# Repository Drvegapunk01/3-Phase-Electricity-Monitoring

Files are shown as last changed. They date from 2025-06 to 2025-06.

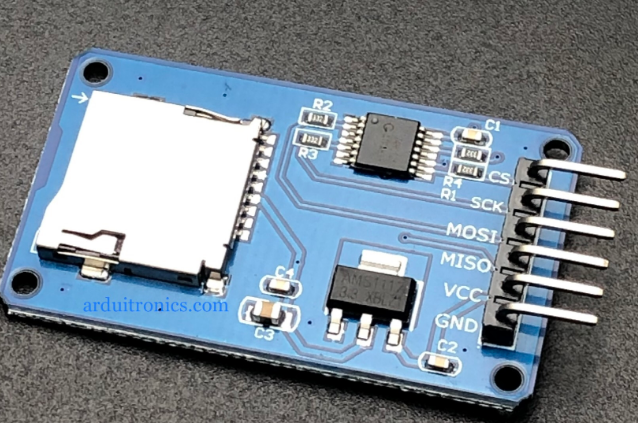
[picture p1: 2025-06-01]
PCB-File/3D-Picture/SD_card module.png

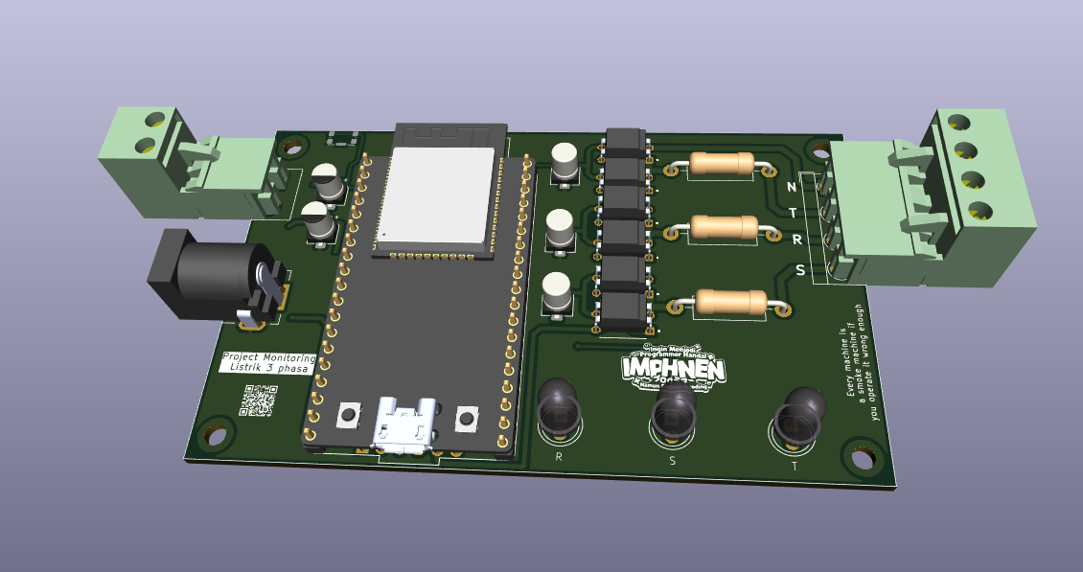
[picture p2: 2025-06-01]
PCB-File/3D-Picture/Screenshot 2025-06-01 153454.png

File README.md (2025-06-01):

# 3-Phase-Electricity-Monitoring

This project is a module to monitor the status of a 3-phase electricity supply and record any power outages. The data can be accessed wirelessly.
Currently, the features are limited to detecting the power state only.

This project was inspired by my father’s question about whether it’s possible to create a device that records power outages at the TV transmitter station where he works.

In the PCB, I use two optocouplers on each phase to capture the full-wave signal. Then, I filter the output with a capacitor to obtain a clean DC signal, which is connected to the ESP32’s I/O pins.

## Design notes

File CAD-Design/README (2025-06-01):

This design is still very bad and unfinished, and I am still learning more to make this case
and I use FreeCad to design this

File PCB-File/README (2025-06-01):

Software yang saya gunakan adalah Kicad 8.0

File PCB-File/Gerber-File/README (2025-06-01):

This is the output Gerber file of this project.

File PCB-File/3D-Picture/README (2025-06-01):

This is a 3D image of this PCB project, and there is also an image of the SD-Card module we are using.

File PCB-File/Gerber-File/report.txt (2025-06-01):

Warning: Width correction constrained.  The width correction value must be in the range of [0.000001 mm; 0.199999 mm] for the current design rules.
Plotted to 'E:\Project\ESP32 RST Monitoring\ESP32 RST Monitoring-F_Cu.gbr'.
Plotted to 'E:\Project\ESP32 RST Monitoring\ESP32 RST Monitoring-B_Cu.gbr'.
Plotted to 'E:\Project\ESP32 RST Monitoring\ESP32 RST Monitoring-F_Paste.gbr'.
Plotted to 'E:\Project\ESP32 RST Monitoring\ESP32 RST Monitoring-B_Paste.gbr'.
Plotted to 'E:\Project\ESP32 RST Monitoring\ESP32 RST Monitoring-F_Silkscreen.gbr'.
Plotted to 'E:\Project\ESP32 RST Monitoring\ESP32 RST Monitoring-B_Silkscreen.gbr'.
Plotted to 'E:\Project\ESP32 RST Monitoring\ESP32 RST Monitoring-F_Mask.gbr'.
Plotted to 'E:\Project\ESP32 RST Monitoring\ESP32 RST Monitoring-B_Mask.gbr'.
Plotted to 'E:\Project\ESP32 RST Monitoring\ESP32 RST Monitoring-Edge_Cuts.gbr'.
Created Gerber job file 'E:\Project\ESP32 RST Monitoring\ESP32 RST Monitoring-job.gbrjob'.
Info: Done.

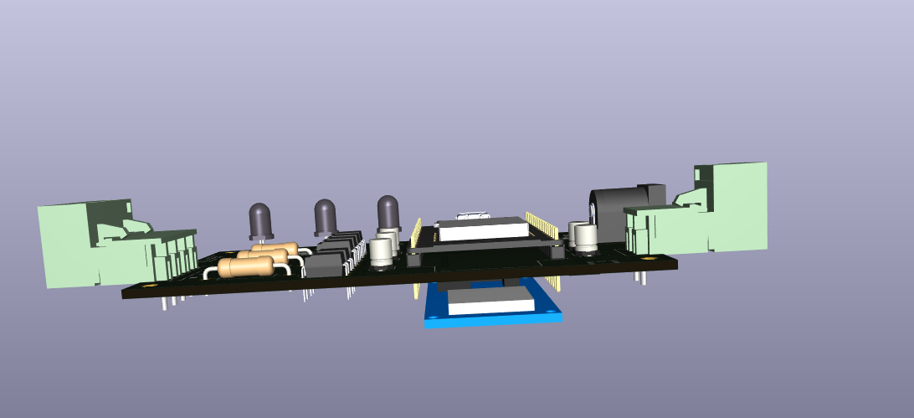
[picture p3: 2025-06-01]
PCB-File/3D-Picture/Screenshot 2025-06-01 154456.png

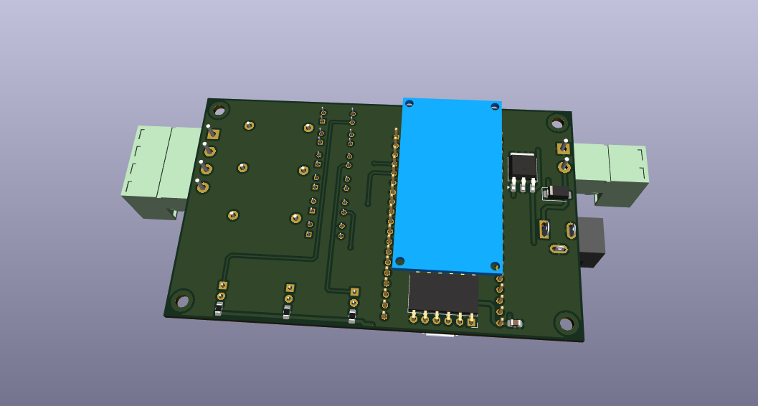
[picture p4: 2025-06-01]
PCB-File/3D-Picture/Screenshot 2025-06-01 154443.png

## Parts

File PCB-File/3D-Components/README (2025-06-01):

These are the 3D components that I used in this project.

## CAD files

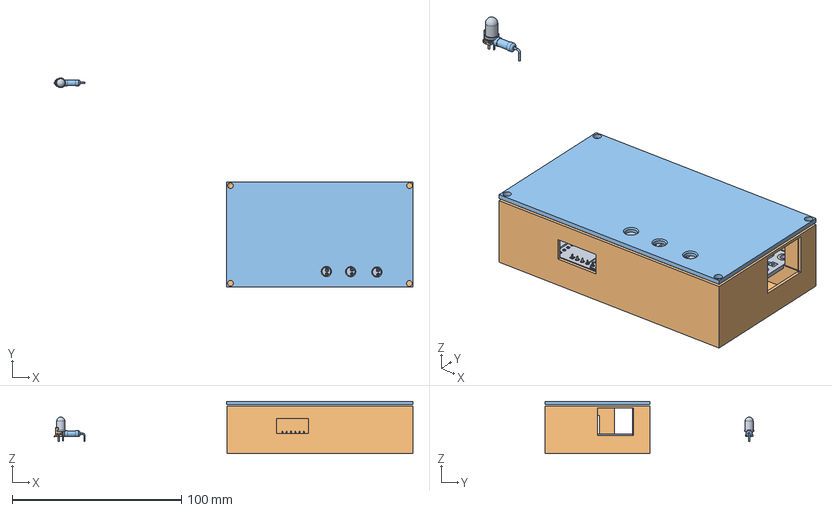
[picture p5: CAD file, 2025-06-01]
CAD-Design/Design 2.FCStd
212.2 x 123.6 x 30.8 mm
LED_D5.0mm_IRGrey
CP_Elec_4x5.4
R_Axial_DIN0411_L9.9mm_D3.6mm_P15.24mm_Horizontal
D_SMA
R_0805_2012Metric
C_0805_2012Metric
PinSocket_1x06_P2.54mm_Horizontal
micro_sdCard
ESP32 RST Monitoring_track_1
ESP32 RST Monitoring_track_2
ESP32 RST Monitoring_track_3
ESP32 RST Monitoring_track_4
ESP32 RST Monitoring_track_5
ESP32 RST Monitoring_track_7
ESP32 RST Monitoring_track_8
ESP32 RST Monitoring_track_9
ESP32 RST Monitoring_track_10
ESP32 RST Monitoring_track_11
ESP32 RST Monitoring_track_12
ESP32 RST Monitoring_track_13
ESP32 RST Monitoring_track_14
ESP32 RST Monitoring_track_15
ESP32 RST Monitoring_track_16
ESP32 RST Monitoring_track_17
ESP32 RST Monitoring_track_18
ESP32 RST Monitoring_track_19
ESP32 RST Monitoring_track_20
ESP32 RST Monitoring_track_21
ESP32 RST Monitoring_track_22
ESP32 RST Monitoring_track_23
ESP32 RST Monitoring_track_24
ESP32 RST Monitoring_track_25
ESP32 RST Monitoring_track_26
ESP32 RST Monitoring_track_27
ESP32 RST Monitoring_track_28
ESP32 RST Monitoring_track_29
ESP32 RST Monitoring_track_30
ESP32 RST Monitoring_track_31
ESP32 RST Monitoring_track_32
ESP32 RST Monitoring_track_33
ESP32 RST Monitoring_track_34
ESP32 RST Monitoring_track_35
ESP32 RST Monitoring_track_36
ESP32 RST Monitoring_track_37
ESP32 RST Monitoring_track_38
ESP32 RST Monitoring_track_39
ESP32 RST Monitoring_track_40
ESP32 RST Monitoring_track_41
ESP32 RST Monitoring_track_42
ESP32 RST Monitoring_track_43
ESP32 RST Monitoring_track_44
ESP32 RST Monitoring_track_45
ESP32 RST Monitoring_track_46
ESP32 RST Monitoring_track_47
ESP32 RST Monitoring_track_48
ESP32 RST Monitoring_track_49
ESP32 RST Monitoring_track_50
ESP32 RST Monitoring_track_51
ESP32 RST Monitoring_track_52
ESP32 RST Monitoring_track_53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

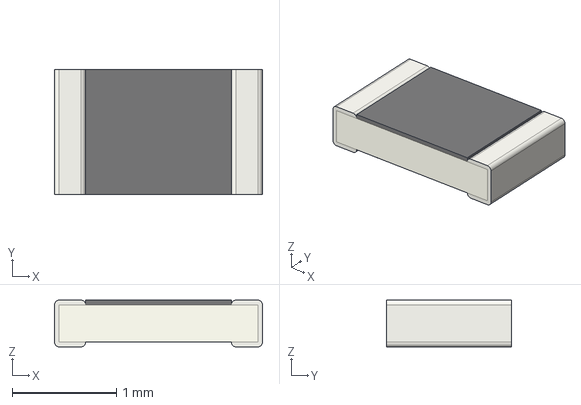
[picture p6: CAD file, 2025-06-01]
PCB-File/3D-Components/R_0805_2012Metric.step
2.00 x 1.20 x 0.45 mm

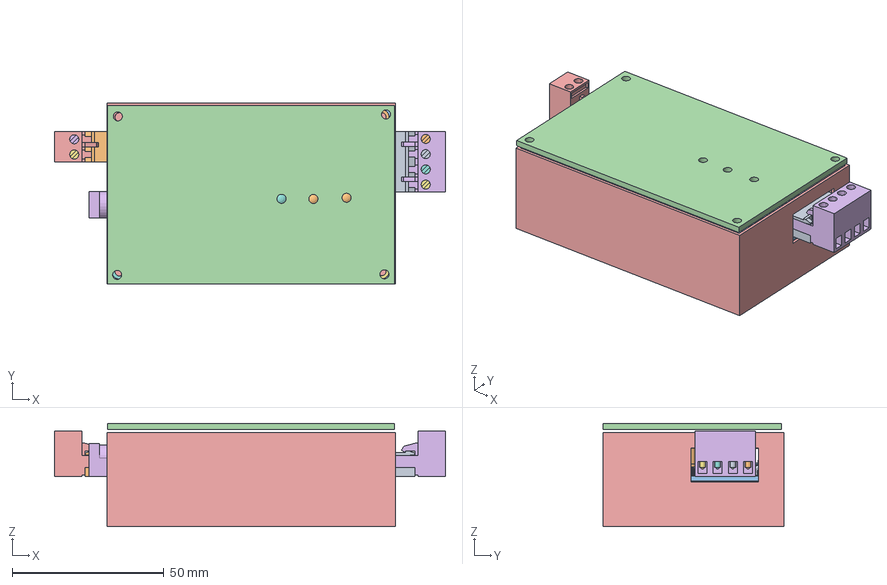
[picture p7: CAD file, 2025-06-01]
CAD-Design/Design 1 (Tahap awal).FCStd
128.7 x 59.7 x 34.0 mm
Terminal-Fonix-4pin
Terminal-Fonix-4pin001
Terminal-Fonix-4pin002
Terminal-Fonix-4pin003
Terminal-Fonix-4pin004
Terminal-Fonix-4pin005
Terminal-Fonix-4pin006
Terminal-Fonix-4pin007
Terminal-Fonix-4pin008
Terminal-Fonix-4pin009
PC817C
PC817C001
PC817C002
PC817C003
PC817C004
LED_D5.0mm_IRGrey
CP_Elec_4x54
LED_D5.0mm_IRGrey002
ESP32-DEVKITC
ESP32-DEVKITC001
ESP32-DEVKITC002
ESP32-DEVKITC003
ESP32-DEVKITC004
ESP32-DEVKITC005
ESP32-DEVKITC006
ESP32-DEVKITC007
ESP32-DEVKITC008
ESP32-DEVKITC009
ESP32-DEVKITC010
ESP32-DEVKITC011
ESP32-DEVKITC012
ESP32-DEVKITC013
ESP32-DEVKITC014
ESP32-DEVKITC015
ESP32-DEVKITC016
ESP32-DEVKITC017
ESP32-DEVKITC018
ESP32-DEVKITC019
ESP32-DEVKITC020
ESP32-DEVKITC021
ESP32-DEVKITC022
ESP32-DEVKITC023
ESP32-DEVKITC024
ESP32-DEVKITC025
ESP32-DEVKITC026
ESP32-DEVKITC027
ESP32-DEVKITC028
ESP32-DEVKITC029
ESP32-DEVKITC030
ESP32-DEVKITC031
ESP32-DEVKITC032
ESP32-DEVKITC033
ESP32-DEVKITC034
ESP32-DEVKITC035
ESP32-DEVKITC036
ESP32-DEVKITC037
ESP32-DEVKITC038
ESP32-DEVKITC039
ESP32-DEVKITC040
ESP32-DEVKITC041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

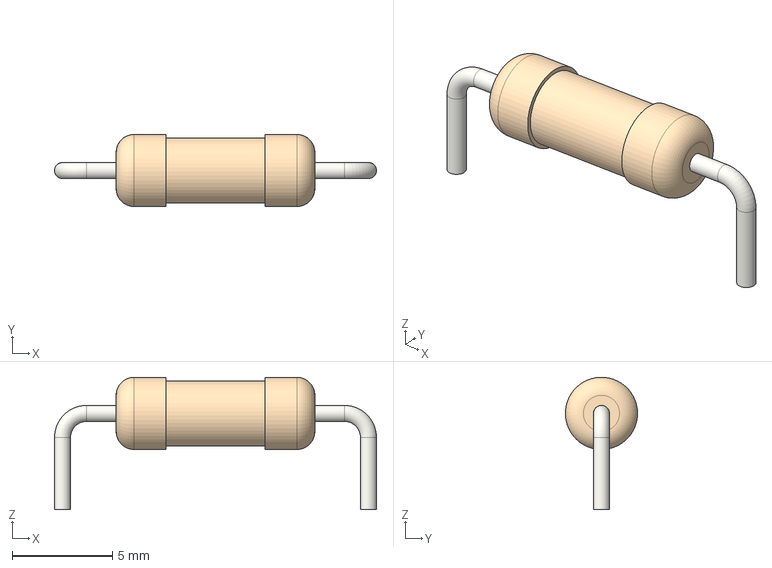
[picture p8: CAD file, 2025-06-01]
PCB-File/3D-Components/R_Axial_DIN0411_L9.9mm_D3.6mm_P15.24mm_Horizontal.step
16.0 x 3.60 x 6.60 mm

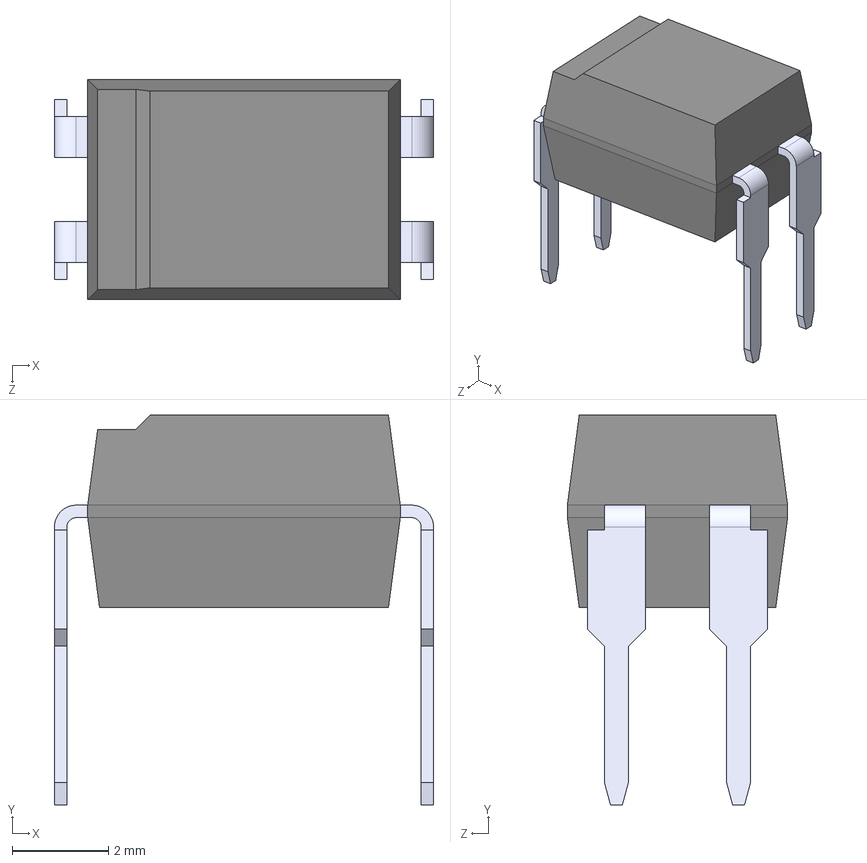
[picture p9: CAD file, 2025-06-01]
PCB-File/3D-Components/PC817C.step
7.88 x 8.10 x 4.58 mm

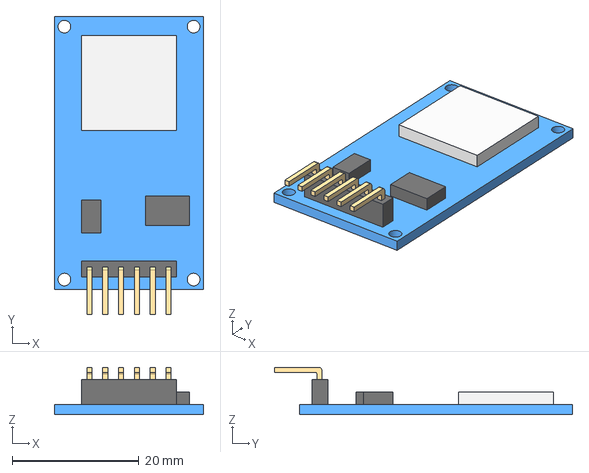
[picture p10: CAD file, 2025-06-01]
PCB-File/3D-Components/micro_sdCard.step
23.6 x 47.1 x 7.50 mm

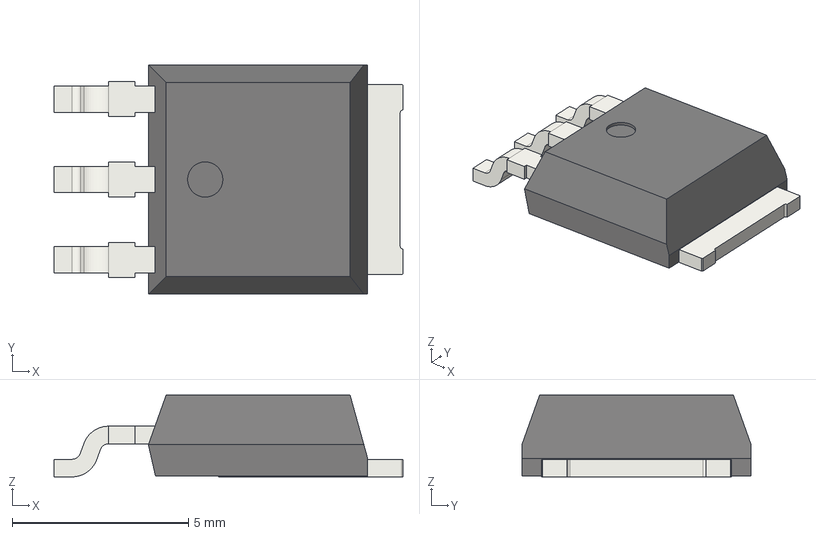
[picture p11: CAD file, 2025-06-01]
PCB-File/3D-Components/TO-252-3_TabPin2.step
9.90 x 6.50 x 2.32 mm
98f8d7e1-9c39-11ed-93f0-dde97e994e83_part
98f8d7e2-9c39-11ed-93f0-dde97e994e83_part
98f8d7e3-9c39-11ed-93f0-dde97e994e83_part

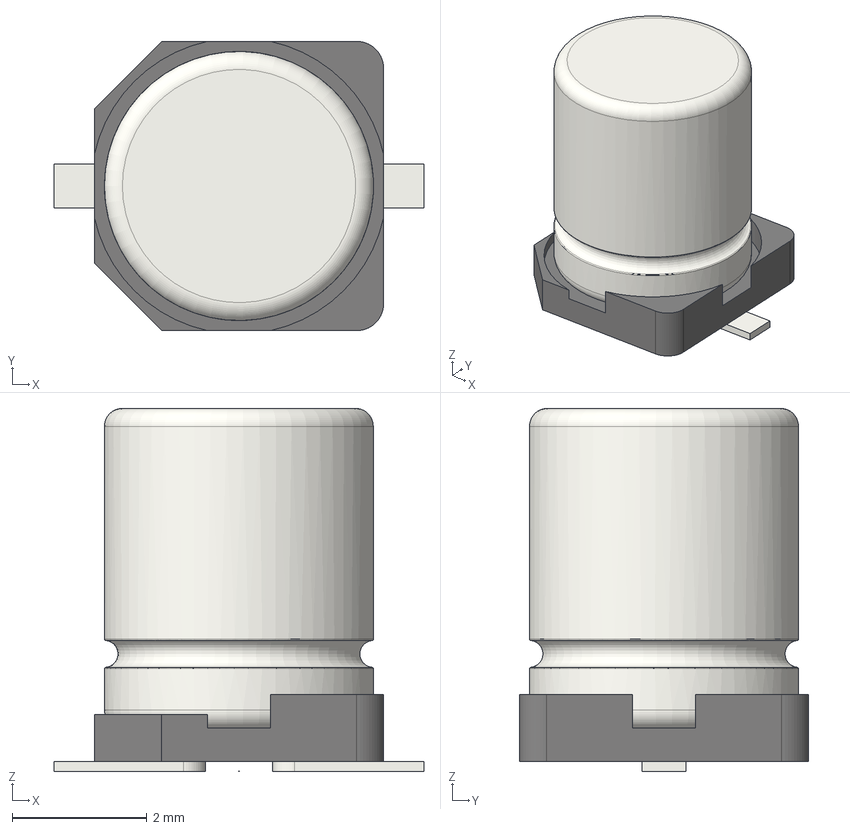
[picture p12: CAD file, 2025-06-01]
PCB-File/3D-Components/C_Elec_4x5.4.step
5.50 x 4.30 x 5.40 mm

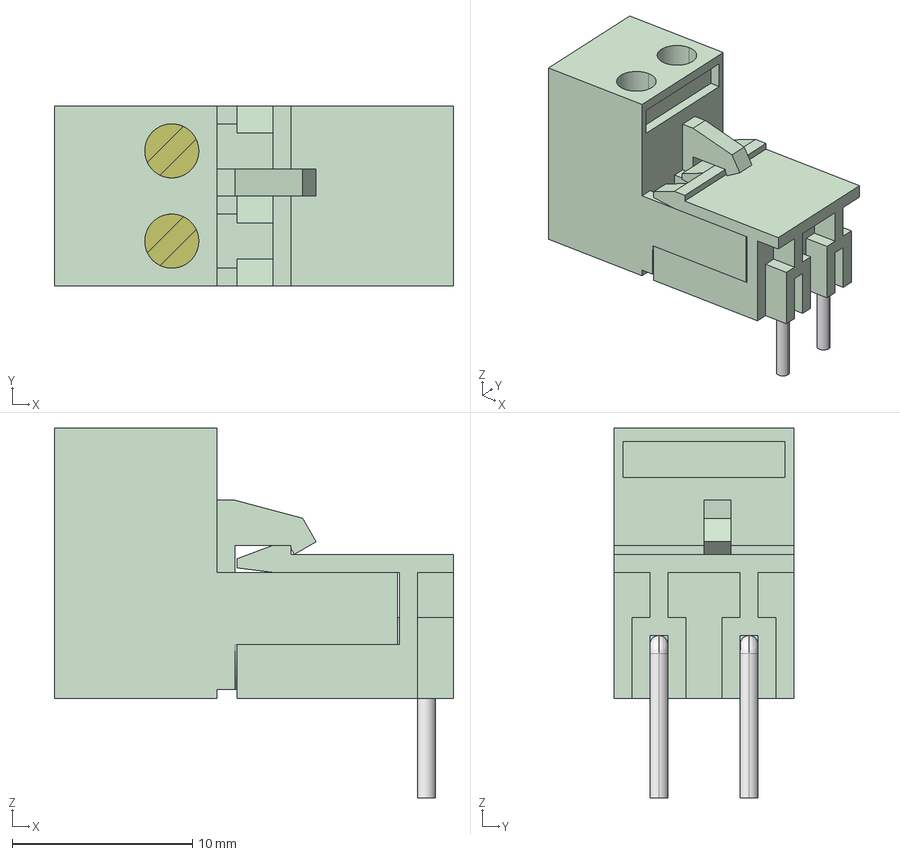
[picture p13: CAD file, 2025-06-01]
PCB-File/3D-Components/2pin.step
22.1 x 10.0 x 20.5 mm
N Geometry
pin
pin001
M Geometry
pich
pich001

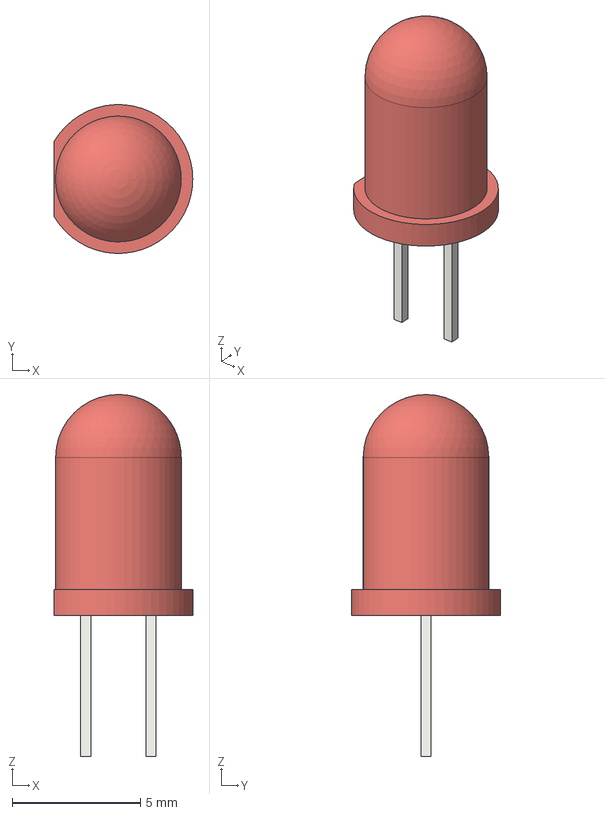
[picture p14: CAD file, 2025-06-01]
PCB-File/3D-Components/LED_D5.0mm.step
5.40 x 5.79 x 14.1 mm

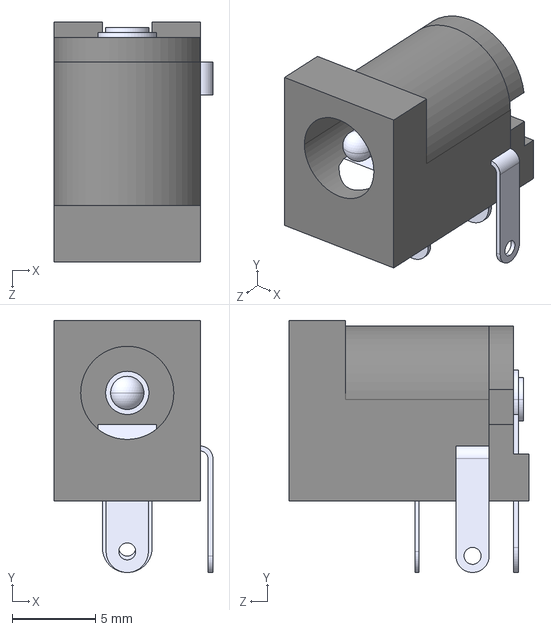
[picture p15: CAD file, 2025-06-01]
PCB-File/3D-Components/EJ508A--3DModel-STEP-56544.STEP
9.55 x 15.2 x 14.4 mm

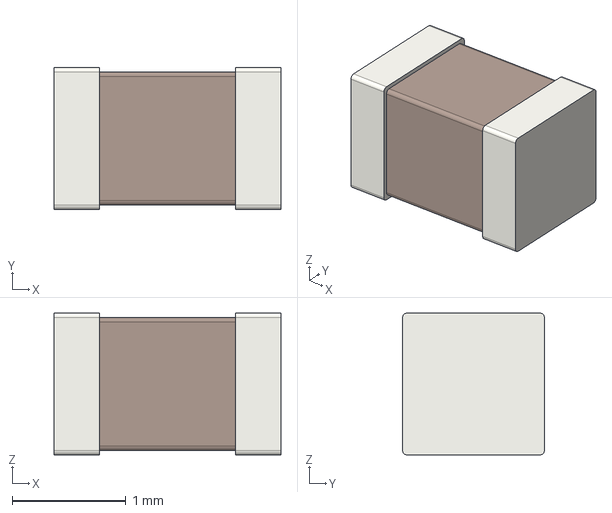
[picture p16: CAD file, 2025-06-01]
PCB-File/3D-Components/C_0805_2012Metric.step
2.00 x 1.25 x 1.25 mm

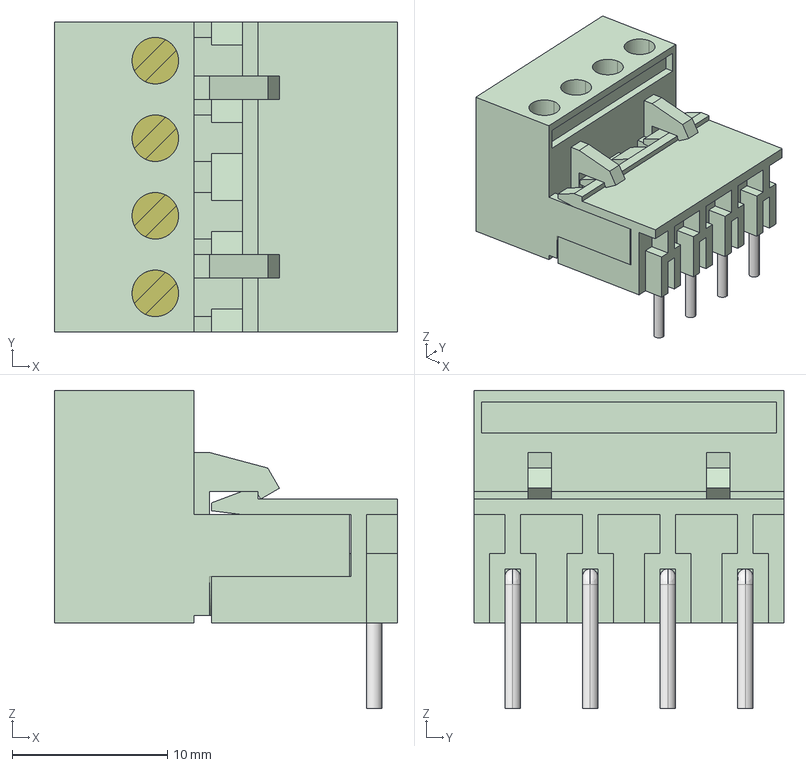
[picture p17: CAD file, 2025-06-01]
PCB-File/3D-Components/4 pin.step
22.1 x 20.0 x 20.5 mm
N3 Geometry
pin3
pin006
pin007
pin008
M3 Geometry
pich3
pich006
pich007
pich008

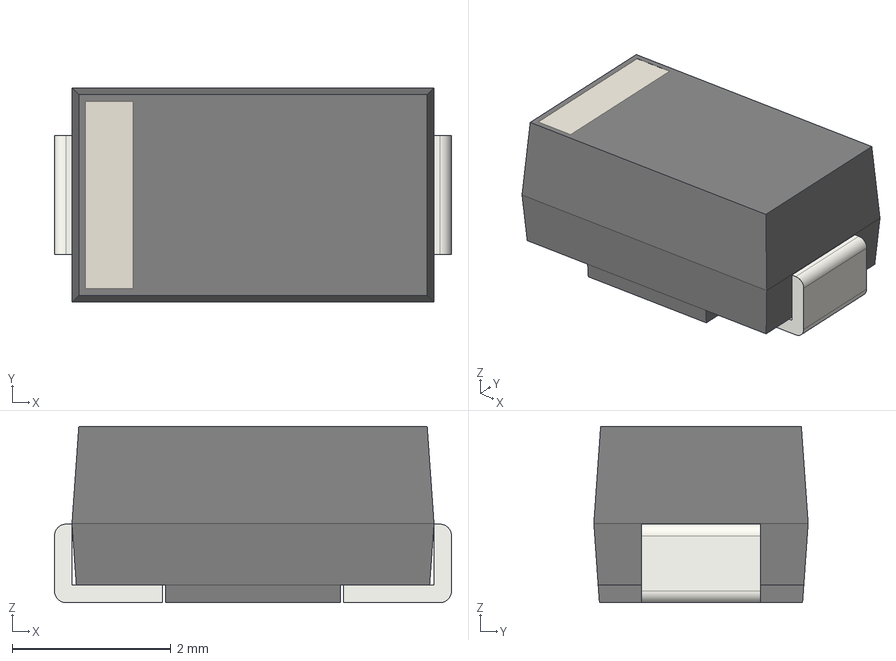
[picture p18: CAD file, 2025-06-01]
PCB-File/3D-Components/D_SMA.step
5.00 x 2.70 x 2.22 mm

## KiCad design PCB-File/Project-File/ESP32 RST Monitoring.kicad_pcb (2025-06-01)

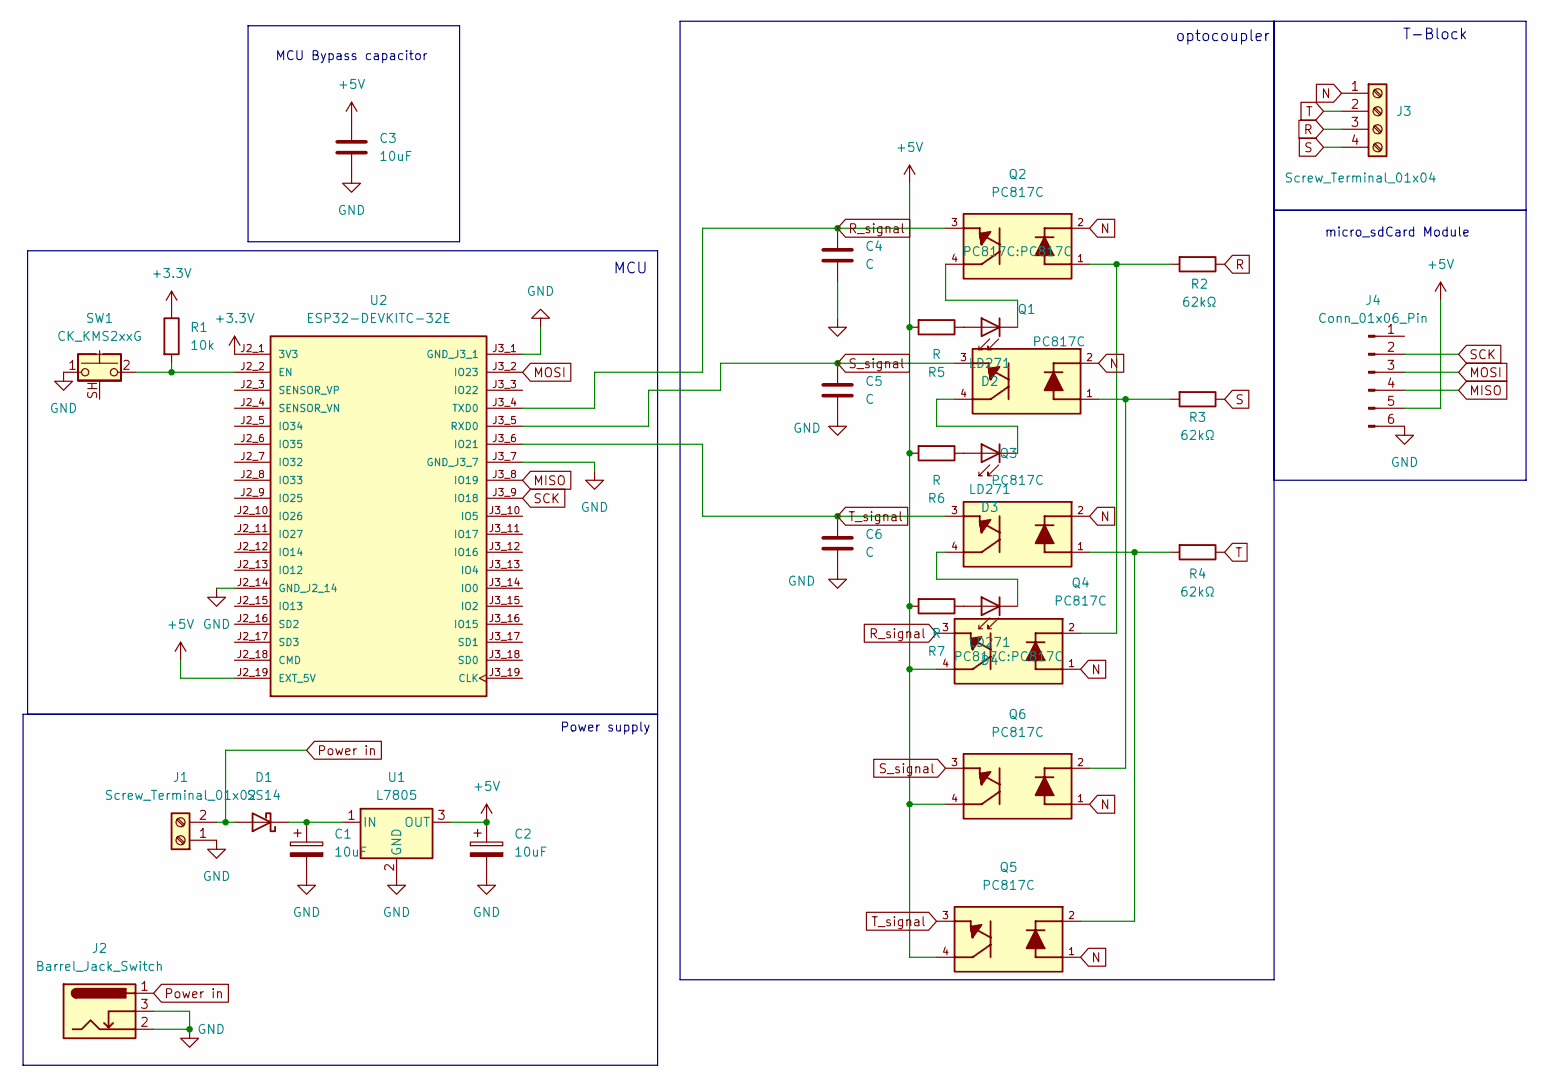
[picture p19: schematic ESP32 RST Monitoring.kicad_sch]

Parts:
C1, C2: 10uF; CP_Elec_4x5.4
C3: 10uF; C_0805_2012Metric_Pad1.18x1.45mm_HandSolder
C4, C5, C6: C; C_Elec_4x5.4
D1: SS14; D_SMA
D2, D3, D4: LD271; LED_D5.0mm_IRGrey
J1: Screw_Terminal_01x02; TerminalBlock_bornier-2_P5.08mm
J2: Barrel_Jack_Switch; BarrelJack_Kycon_KLDX-0202-xC_Horizontal
J3: Screw_Terminal_01x04; TerminalBlock_MetzConnect_Type011_RT05504HBWC_1x04_P5.00mm_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
J4: Conn_01x06_Pin; PinSocket_1x06_P2.54mm_Horizontal
Q1, Q2, Q3, Q4, Q5, Q6: PC817C; PARTREV N/A
R1: 10k; R_0805_2012Metric_Pad1.20x1.40mm_HandSolder
R2, R3, R4: 62kΩ; R_Axial_DIN0411_L9.9mm_D3.6mm_P15.24mm_Horizontal
R5, R6, R7: R; R_0805_2012Metric_Pad1.20x1.40mm_HandSolder
SW1: CK_KMS2xxG; SW_SPST_CK_KMS2xxG
U1: L7805; TO-252-3_TabPin2
U2: ESP32-DEVKITC-32E; MODULE_ESP32-DEVKITC-32E; PARTREV 1.4

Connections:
+3.3V: R1.1, U2.J2_1 (3V3)
+5V: C2.1, C3.1, J4.5, Q4.4, Q5.4, Q6.4, R5.2, R6.2, R7.2, U1.3 (OUT), U2.J2_19 (EXT_5V)
GND: C1.2, C2.2, C3.2, C4.2, C5.2, C6.2, J1.1, J2.2, J2.3, J4.6, SW1.1, U1.2 (GND), U2.J2_14 (GND_J2_14), U2.J3_1 (GND_J3_1), U2.J3_7 (GND_J3_7)
MISO: J4.4, U2.J3_8 (IO19)
MOSI: J4.3, U2.J3_2 (IO23)
N: J3.1, Q1.2, Q2.2, Q3.2, Q4.1, Q5.1, Q6.1
unnamed: C1.1, D1.1 (K), U1.1 (IN)
unnamed: D2.2 (A), R5.1
unnamed: D2.1 (K), Q2.4
unnamed: D3.2 (A), R6.1
unnamed: D3.1 (K), Q1.4
unnamed: D4.2 (A), R7.1
unnamed: D4.1 (K), Q3.4
unnamed: Q1.1, Q6.2, R3.2
unnamed: Q2.1, Q4.2, R2.2
unnamed: Q3.1, Q5.2, R4.2
unnamed: R1.2, SW1.2, U2.J2_2 (EN)
Power in: D1.2 (A), J1.2, J2.1
R: J3.3, R2.1
R_signal: C4.1, Q2.3, Q4.3, U2.J3_4 (TXD0)
S: J3.4, R3.1
SCK: J4.2, U2.J3_9 (IO18)
S_signal: C5.1, Q1.3, Q6.3, U2.J3_5 (RXD0)
T: J3.2, R4.1
T_signal: C6.1, Q3.3, Q5.3, U2.J3_6 (IO21)

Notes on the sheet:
micro_sdCard Module
MCU Bypass capacitor
optocoupler
Power supply
T-Block
MCU

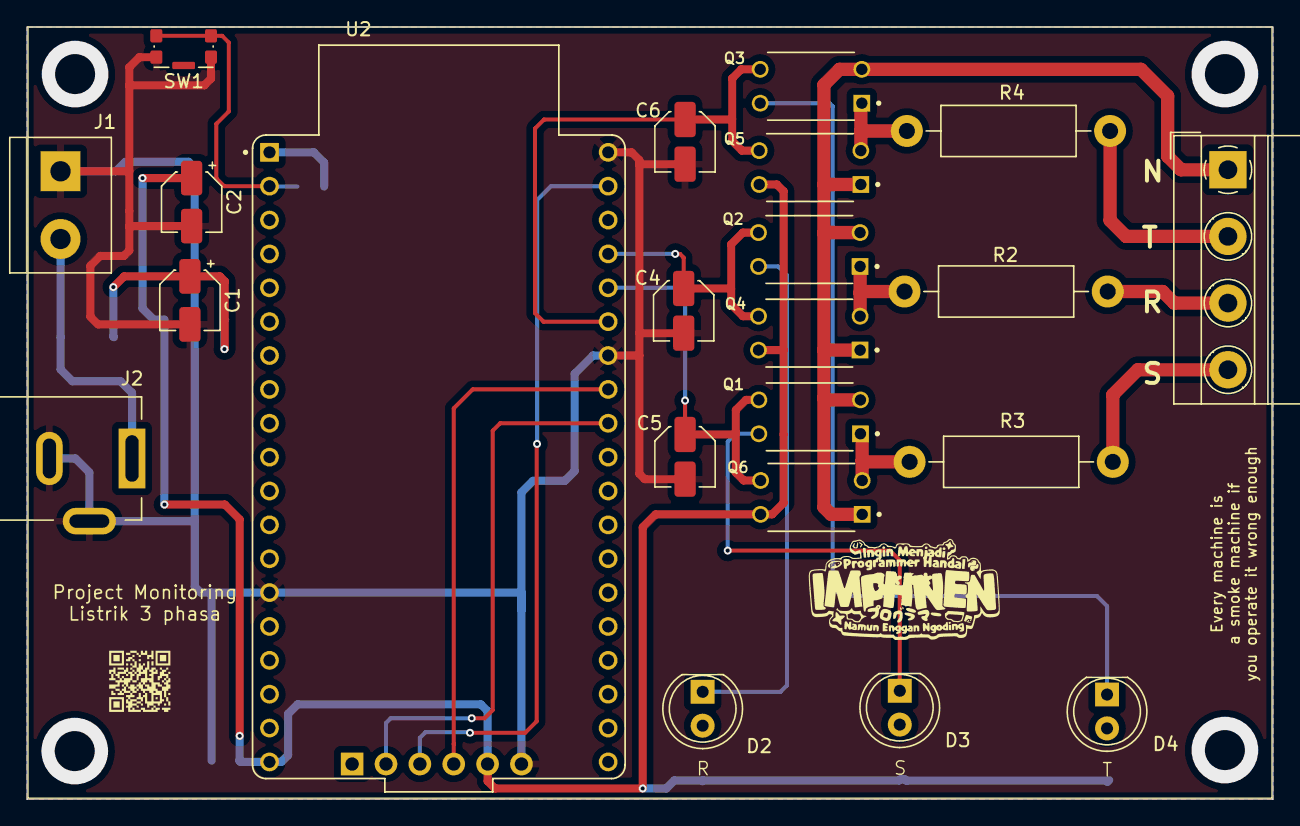
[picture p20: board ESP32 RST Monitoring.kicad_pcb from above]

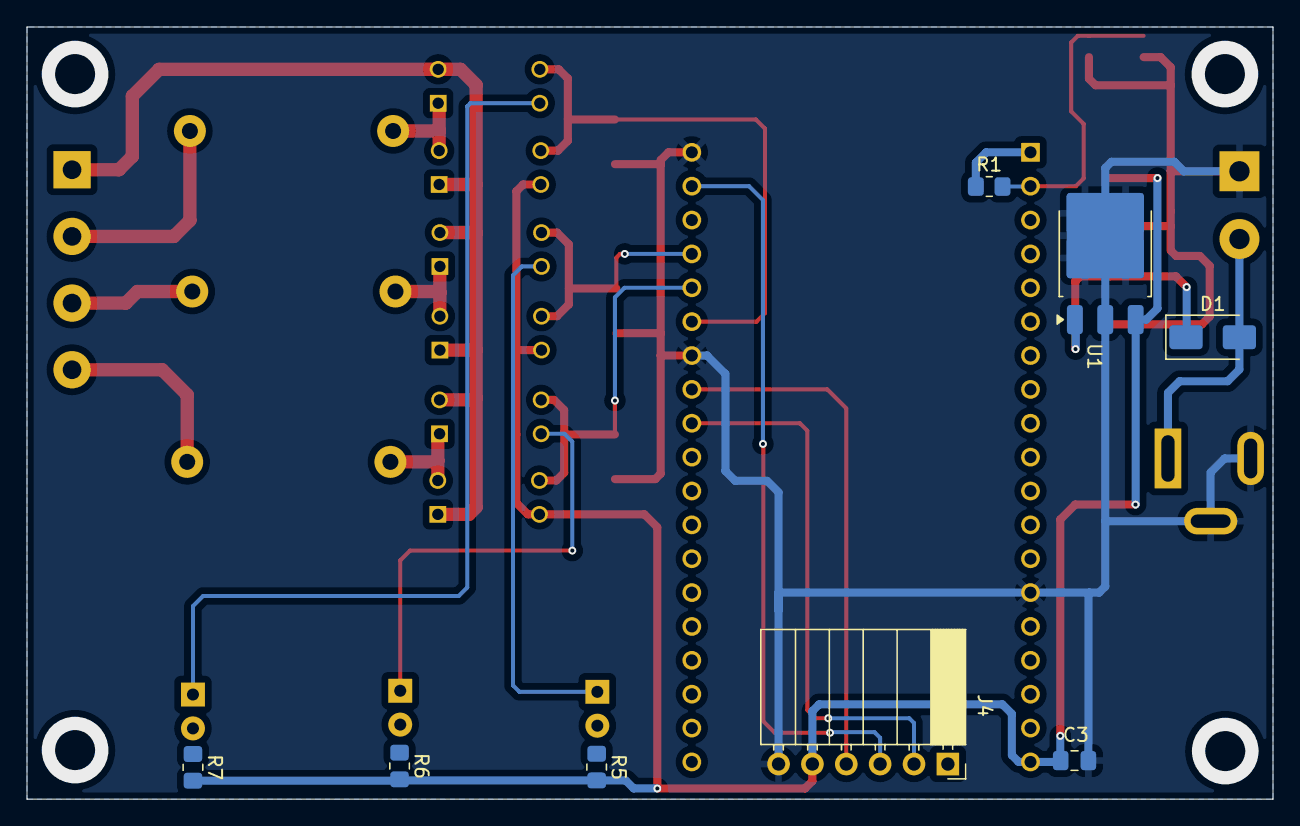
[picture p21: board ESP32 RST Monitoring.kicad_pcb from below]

Board: 2 copper layers, 93.4 x 57.9 mm, 30 parts (8 on the bottom side), 25 nets.

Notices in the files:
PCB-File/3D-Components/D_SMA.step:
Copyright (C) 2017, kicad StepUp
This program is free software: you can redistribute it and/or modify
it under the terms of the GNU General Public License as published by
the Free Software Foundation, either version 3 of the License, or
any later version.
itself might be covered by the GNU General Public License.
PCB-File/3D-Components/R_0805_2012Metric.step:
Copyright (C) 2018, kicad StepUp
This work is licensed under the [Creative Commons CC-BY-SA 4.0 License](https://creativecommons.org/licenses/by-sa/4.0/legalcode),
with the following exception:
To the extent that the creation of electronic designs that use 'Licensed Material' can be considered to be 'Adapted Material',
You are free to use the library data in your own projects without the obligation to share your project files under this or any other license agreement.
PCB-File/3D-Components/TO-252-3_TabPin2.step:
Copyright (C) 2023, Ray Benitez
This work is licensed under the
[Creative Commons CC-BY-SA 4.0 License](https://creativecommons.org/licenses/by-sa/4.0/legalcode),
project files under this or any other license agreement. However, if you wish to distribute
